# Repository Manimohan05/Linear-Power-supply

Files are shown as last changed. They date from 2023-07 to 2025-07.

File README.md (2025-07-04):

# Linear Power Supply Design

## Abstract

This project, part of the EN2111 Electronic Circuit Design module at the University of Moratuwa, focuses on designing a linear power supply with a maximum current limit of 100 mA, incorporating over-current protection. The power supply delivers a stable output voltage adjustable from 8V to 14V, robust against fluctuating input voltages (16V to 20V) and varying load conditions. This repository contains the project files, including schematics, PCB designs, calculations, and documentation, developed by Group 19 under the supervision of Dr. Thusapparan Subramaniam.

## Introduction

A linear power supply provides a stable, precise output voltage, unlike unregulated power supplies that vary with load and input voltage fluctuations. By using a linear regulator, the power supply maintains a consistent output voltage (adjustable from 8V to 14V), reduces ripple and noise in the output direct current, and includes current limiting to protect against over-current damage. Key performance metrics include:
- **Line Regulation**: The ability to maintain the specified output voltage despite input voltage variations (16V to 20V).
- **Load Regulation**: The ability to maintain the specified output voltage under varying load conditions (e.g., resistors from 6Ω to 5000Ω).
- **Over-Current Protection**: Limits the output current to ~100 mA to safeguard the power supply and connected circuits.

The worst-case tolerance for output voltage stability is the sum of line and load regulation percentages. This project demonstrates the design, implementation, and testing of a linear power supply to meet these requirements.

## Project Objectives

- Design a linear power supply with an adjustable output voltage of 8V to 14V.
- Implement a current limit of 100 mA with over-current protection.
- Ensure output stability against input voltage fluctuations (16V to 20V) and varying load conditions.
- Prototype the circuit on a breadboard and finalize with a PCB design using EasyEDA.
- Document the design process, calculations, and performance results.

## Key Features

- **Voltage Regulation**: Utilizes a Zener diode and resistors to achieve stable output with minimal ripple and noise.
- **Current Limiting**: Targeted at 100 mA, achieved ~103 mA due to component tolerances.
- **Transistor**: TIP31C selected for power dissipation capacity exceeding 1.2W [(20V - 8V) × 100 mA].
- **PCB Design**: Designed with EasyEDA, adhering to rules such as 0.152 mm clearance, 0.254 mm copper width, and a 46 mm × 31 mm board.
- **Testing**: Validated for line and load regulation across input voltages (16V to 20V) and load conditions.

## Setup Instructions

### Prerequisites

- **Software**:
  - EasyEDA for viewing/editing schematic and PCB files.
  - A PDF reader for documentation.
  - A spreadsheet viewer (e.g., Microsoft Excel, LibreOffice Calc) for calculation files.
- **Hardware** (for replication):
  - TIP31C transistor.
  - Zener diode (refer to project documentation for selection details).
  - Resistors, capacitors, and other components as specified in the report.
  - Breadboard and jumper wires for prototyping.
  - PCB fabrication service for the final board.

### Steps to Replicate

1. **Clone the Repository**:
   ```bash
   git clone https://github.com/<your-username>/Linear-Power-Supply.git
   cd Linear-Power-Supply
   ```

2. **Review Documentation**:
   - Open the project report PDF for details on calculations, schematics, and observations.
   - Refer to calculation files for input/output voltage ranges, Zener diode selection, and resistor values.

3. **Breadboard Implementation**:
   - Build the circuit on a breadboard using the schematic provided in the project files.
   - Test with input voltages from 16V to 20V, verifying output voltage (8V to 14V) and current limit (~100 mA).

4. **PCB Design**:
   - Open the EasyEDA schematic and PCB files.
   - Verify PCB design rules (e.g., 0.3 mm hole size, 46 mm × 31 mm board).
   - Use Gerber files for PCB fabrication.

5. **Testing**:
   - Test line regulation by setting the output to 8V and varying the input from 16V to 20V.
   - Test load regulation with resistors from 6Ω to 5000Ω.
   - Confirm current limitation at ~100 mA to ensure over-current protection.

## Observations

- **Output Voltage Range**: Achieved 6.8325V to 14.1534V, slightly wider than the target due to component tolerances.
- **Current Limitation**: Recorded at 103 mA, slightly above the 100 mA target.
- **Line Regulation**: Stable output (e.g., 8V) across input voltages from 16V to 20V, demonstrating effective regulation.
- **Load Regulation**: Consistent output voltage across load resistors from 6Ω to 5000Ω, as documented in the load variance table.

## Challenges

- **Component Selection**: Sourcing precise Zener diodes and resistors was challenging, leading to minor deviations in output.
- **Component Damage**: Improper connections during breadboard testing damaged some BC109 transistors.
- **Output Range**: Initial designs required iterative adjustments to achieve the target voltage range.

## License

This project is licensed under the MIT License. See the `LICENSE` file for details.

## Acknowledgments

- **Supervisors**: Dr. Thusapparan Subramaniam.
- **Institution**: Department of Electronic & Telecommunication Engineering, University of Moratuwa.
- **Tools**: EasyEDA for PCB design, breadboard for prototyping.

For more details, refer to the project report in the repository. Contributions or feedback are welcome—please open an issue or submit a pull request!

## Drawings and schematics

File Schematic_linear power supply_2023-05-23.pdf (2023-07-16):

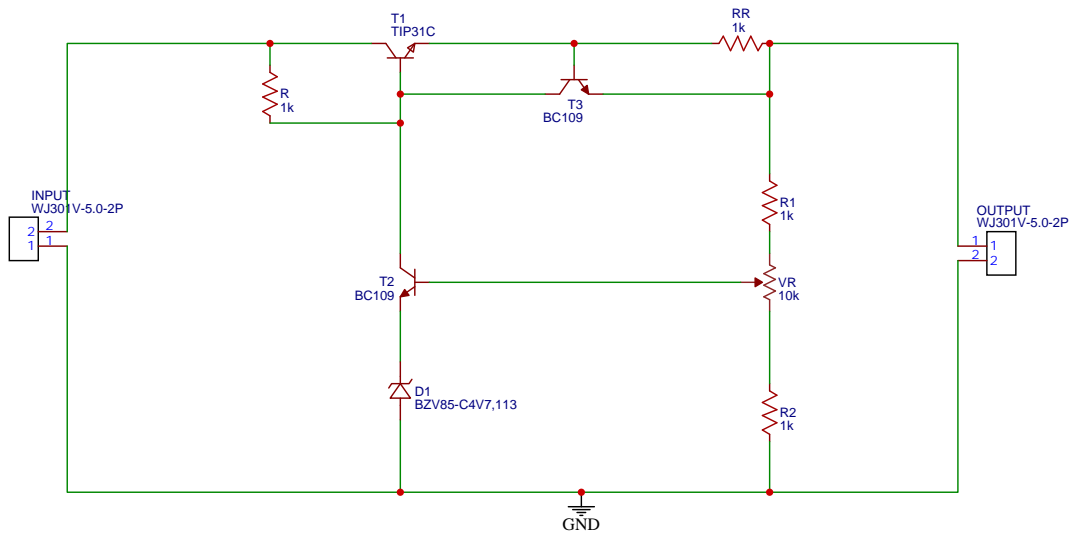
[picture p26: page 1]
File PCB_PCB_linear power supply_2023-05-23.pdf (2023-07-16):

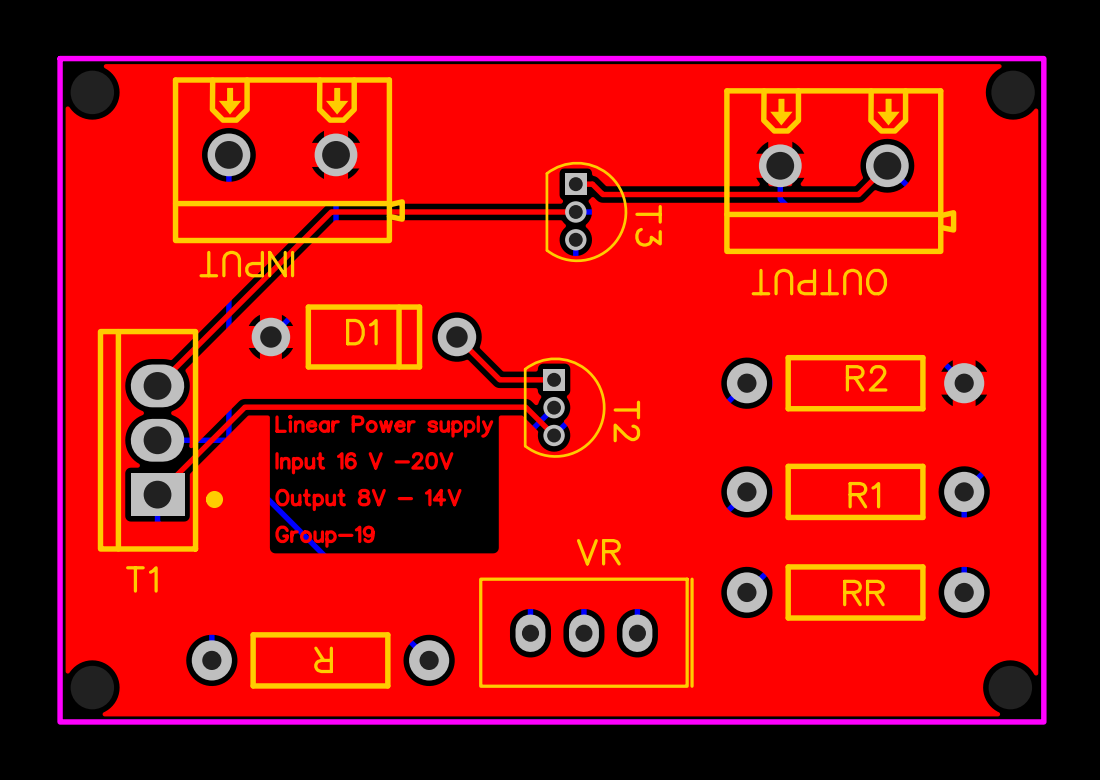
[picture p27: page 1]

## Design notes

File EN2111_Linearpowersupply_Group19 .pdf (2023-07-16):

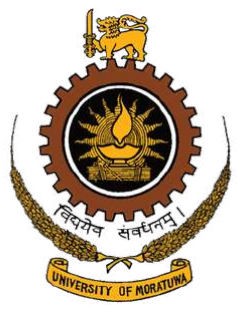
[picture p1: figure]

Department of Electronic & Telecommunication Engineering University of Moratuwa

EN2111 - ELECTRONIC CIRCUIT DESIGN

LINEAR POWER SUPPLY DESIGN

Supervisors:
Dr. Thayaparan Subramaniam
MANIMOHAN T. | 200377M
MIRANDA C.M.C.C. | 200396U
METHSARANI H.E.N | 200395P

This report is submitted as the fulfillment of Lab-03 of module EN2111

21st May 2023

ABSTRACT

We had to create a linear power supply with a maximum current restriction (also known as over-current protection).Our power source need to be able to deliver consistent output voltage for various variable output loads as well as to a fluctuating input line voltage.

This report explains the functionality of Linear power supply which can give output as from 8V to 14V.This is bassed on the module EN2111 - Electronic Circuit Design, Which is conducted by Dr. Thayaparan Subramaniam.

i

TABLE OF CONTENTS

2.4 Selection of variable
resistor(VR) 3

ii

LIST OF TABLES

1 | Current Limitation | | 8
2 | Line variance | 10
3 | load variance | 10
4 | List of components | 12
| LIST OF FIGURES
1 | Circuit | | 1
2 | Breadboard Implementation | | 5
3 | Breadboard Implementation | | 5
4 | Output voltages at minimum Input(16V) | | 6
5 | Output voltages at Input= 17V | | 6
6 | Output voltages at Input= 18V | | 6
7 | Output voltages at Input= 19V | | 7
8 | Output voltages at maximum Input(20V) | | 7
9 | Set Output voltage to 10V | | 7
10 | Set Output voltage to 10V and change the input | | 8
11 | Current Limitation-Vast range | | 9
12 | Current Limitation-Zoomed in small range | | 9
13 | Line Variance | 10
14 | Load Variance-Vast range | 11
15 | Load Variance-Zoomed in small range | 11
16 | Circuit simulation-Minimum Voltage | 12
17 | Circuit simulation-Maximum Voltage | 13
18 | PCB Schematic | 13
19 | PCB 2D View | 14
20 | PCB 3D model | 14

iii

### 1 INTRODUCTION OF LINEAR POWER SUPPLY

* Output voltage of an unregulated power supply will vary depending on the load and on variations in the AC supply voltage
* Linear regulator may be used to set the voltage to a precise value, stabilized against fluctuations in input voltage and load
* Regulator also greatly reduces the ripple and noise in the output direct current
* Linear regulators often provide current limiting, protecting the power supply and attached circuit from over-current
* Adjustable linear power supplies allow the output voltage to be adjusted over a range
* Line regulation is a measure of the circuit’s ability to maintain the specified output voltage with varying input voltage
* Load regulation is a measure of the circuit’s ability to maintain the specified output voltage under varying load conditions.
* Load regulation and Line regulation values apply to the output
* The worst case value is the addition of both line and load tolerance percentages.

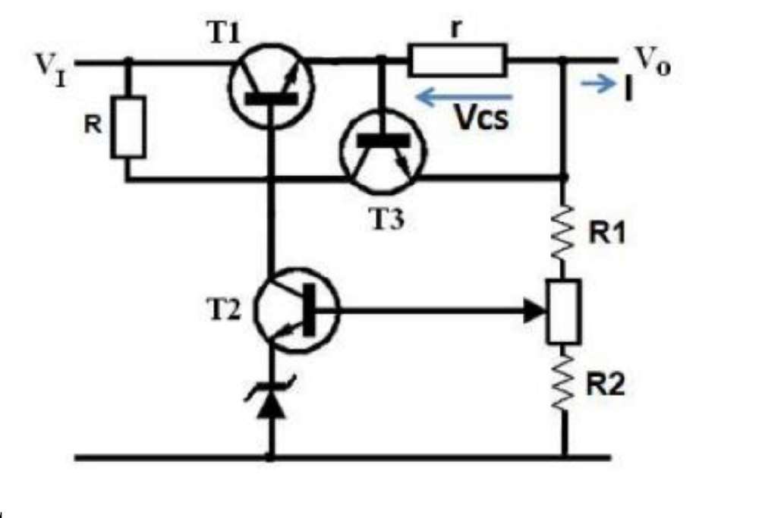
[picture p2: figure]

Figure 1 — Circuit

1

### 2 CALCULATIONS

### 2.1 Calculate Input & Output ranges

* Group Number = 19
* Typical input voltage = 14V + Reminder of (19/5)= 14 + 4 V = 18 V * Input voltage range Vi = Typical Input voltage ± 2 V = 18 ± 2 V
* Current Limitation = 100 mA (for all groups)
* Mid output voltage Vo = Vi - 8 + Reminder of (19 /3) = 11 V
* Output voltage range = Mid output voltage ± 3 V = 11 ± 3 V

### 2.2 Selection of Zener

Vomin > Vz + Vbe
Vz < 7.4V

Therefore we decided to take more zener diode with 4.7V zener voltage.

### 2.3 Calculate R1 and R2

Vo.

R2
R1 + R2

= (VZ + VBE)

VZ = 4.7V

VBE = 0.62V

Vo.

R2
R1 + R2

= 5.32V

(1)

To calculate the maximum ratio between R1 and R2

VOMax = 15V

1 +

R1
R2

=

15V
5.32V
R1
R2

= 2.8195 − 1 = 1.8915

R1

R2 Max

= 1.8915

(2)

To calculate the minimum ratio between R1 and R2

VOM in = 7V

1 +

R1
R2

=

7V
5.32V
R1
R2

= 1.3158 − 1 = 0.3158

R1

R2 M in

= 0.3158

(3)

2

EN 2111:Linear Power Supply Design

let R2 = 5kΩ
For VOMax→ R1 = 1.8195 × 5kΩ = 9.0975kΩ For VOM in→ R1 = 0.3158 × 5kΩ = 1.579kΩ δR1 = (0.0975 − 1.579)kΩ

δR1 = 7.5185kΩ

Therefore, we have selected R1 as 1.5 kohms
R2 as 5 kohms

### 2.4 Selection of variable resistor(VR)

To find VR

VR ≥ δR1 = 7.5185kΩ

Therefore, we have selected 10 kohms variable resistor.

### 2.5 Calculate value of R

To calculate the value of R

IRmin ≥

ILMax
β

+ IKnee

16 − (14 + 0.62)
R

≥

100 × 10−3

100

+ 1 × 10−3

R ≤

1.38 × 10−3

2
R ≤ 0.69 × 10−3

R ≤ 690Ω

(4)

Therefore, we have selected R as 650 Ω

### 2.6 Calculate value of r

To calculate the value of r
To make T3 transistor in active region, the voltage across the base and emitter must be 0.62V, hence VcE must be 0.62V. Since 100mA should be the maximum current allowed to flow through the resistor,

r ≥

0.62V
100 × 10−3A
r ≥ 6.2Ω

(5)

Therefore, we have selected r as 6.8 Ω

### 2.7 Selection of Transistor

T1 transistor’s maximum power dissipation is
(VI max − Vo min) · Imax = (20V − 8V ) · 100mA = 1.2W.
Therefore we chose TIP31C transistor which has a power rating higher than 1.2W.

### 3 METHODOLOGY & OBSERVATIONS

### 3.1 Functionality description

* Current limiting should be 100 mA
* We should be able to change the input and same time output voltage should be constant * Output voltage should be adjustable

### 3.2 Breadboard Implementation

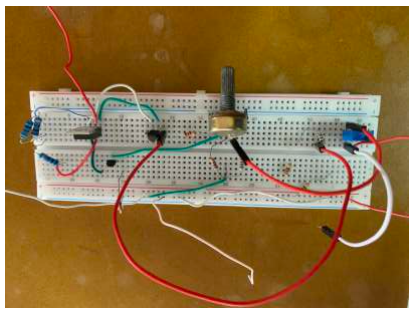
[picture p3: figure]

Figure 2 — Breadboard Implementation

### 3.3 Observations

We achieved a voltage range of 6.8325 V to 14.1534 V and a maximum current of 103 mA due to changes in resistors and impedance.

### 3.3.1 Circuit connections

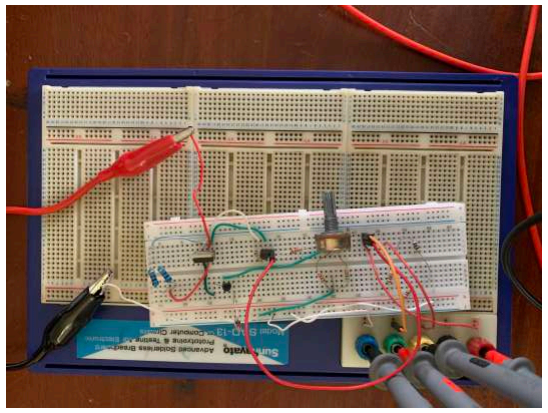
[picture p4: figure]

Figure 3 — Breadboard Implementation

5

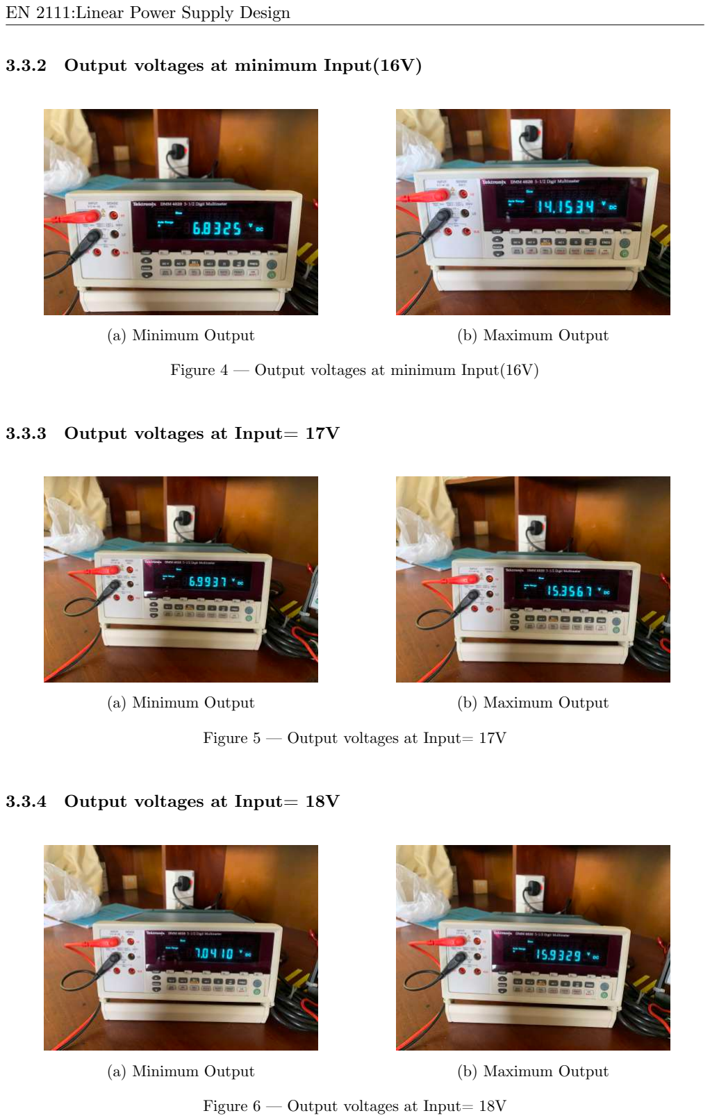
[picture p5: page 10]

### 3.3.2 Output voltages at minimum Input(16V)

(a) Minimum Output | (b) Maximum Output

Figure 4 — Output voltages at minimum Input(16V)

### 3.3.3 Output voltages at Input= 17V

(a) Minimum Output | (b) Maximum Output

Figure 5 — Output voltages at Input= 17V

### 3.3.4 Output voltages at Input= 18V

(a) Minimum Output | (b) Maximum Output

Figure 6 — Output voltages at Input= 18V

### 3.3.5 Output voltages at Input= 19V

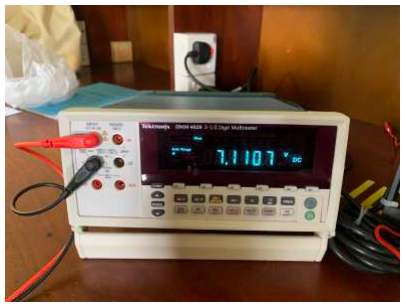
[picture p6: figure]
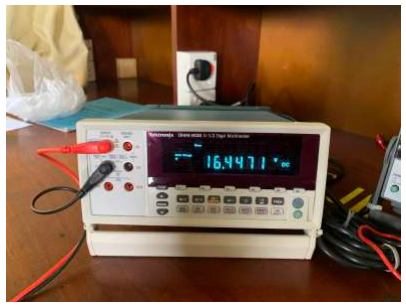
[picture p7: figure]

(a) Minimum Output | (b) Maximum Output

Figure 7 — Output voltages at Input= 19V

### 3.3.6 Output voltages at maximum Input(20V)

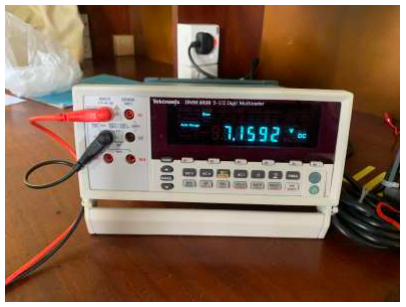
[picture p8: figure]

(a) Minimum Output | (b) Maximum Output

Figure 8 — Output voltages at maximum Input(20V)

### 3.3.7 Set Output voltage to 10V

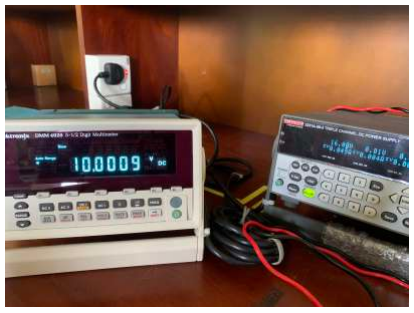
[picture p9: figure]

Figure 9 — Set Output voltage to 10V

### 3.3.8 Change the Input at particular output voltage = 10V

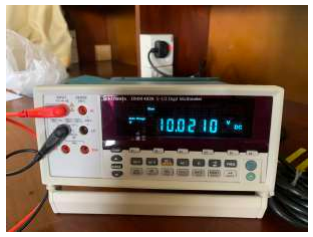
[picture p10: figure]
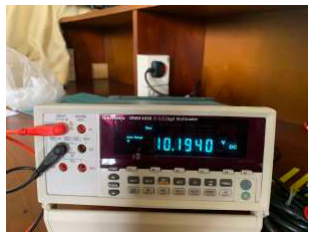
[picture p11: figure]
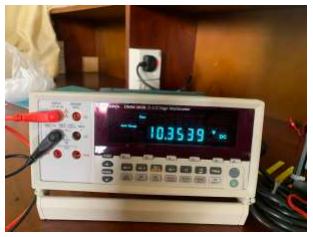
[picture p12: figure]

(a) Input = 16V | (b) Input = 17V | (c) Input = 18V

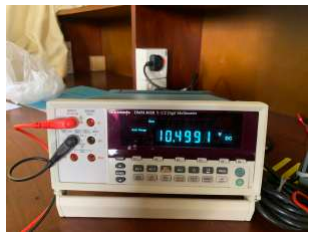
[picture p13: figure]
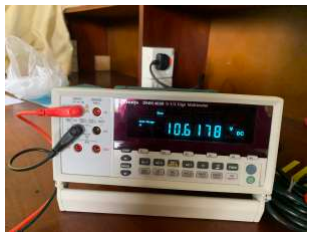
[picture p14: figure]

(d) Input = 19V | (e) Input = 20V

Figure 10 — Set Output voltage to 10V and change the input

### 3.4 Results of Laboratory Implementation

### 3.4.1 Current Limitation

Load Resistor(ohms) | Load current(mA)
6 | 103.00
25 | 102.00
56 | 99.60
71 | 99.40
240 | 40.20
500 | 21.05
750 | 13.62
1000 | 10.23
2000 | 4.02
3000 | 2.49
4000 | 2.01
5000 | 1.84

Table 1 — Current Limitation

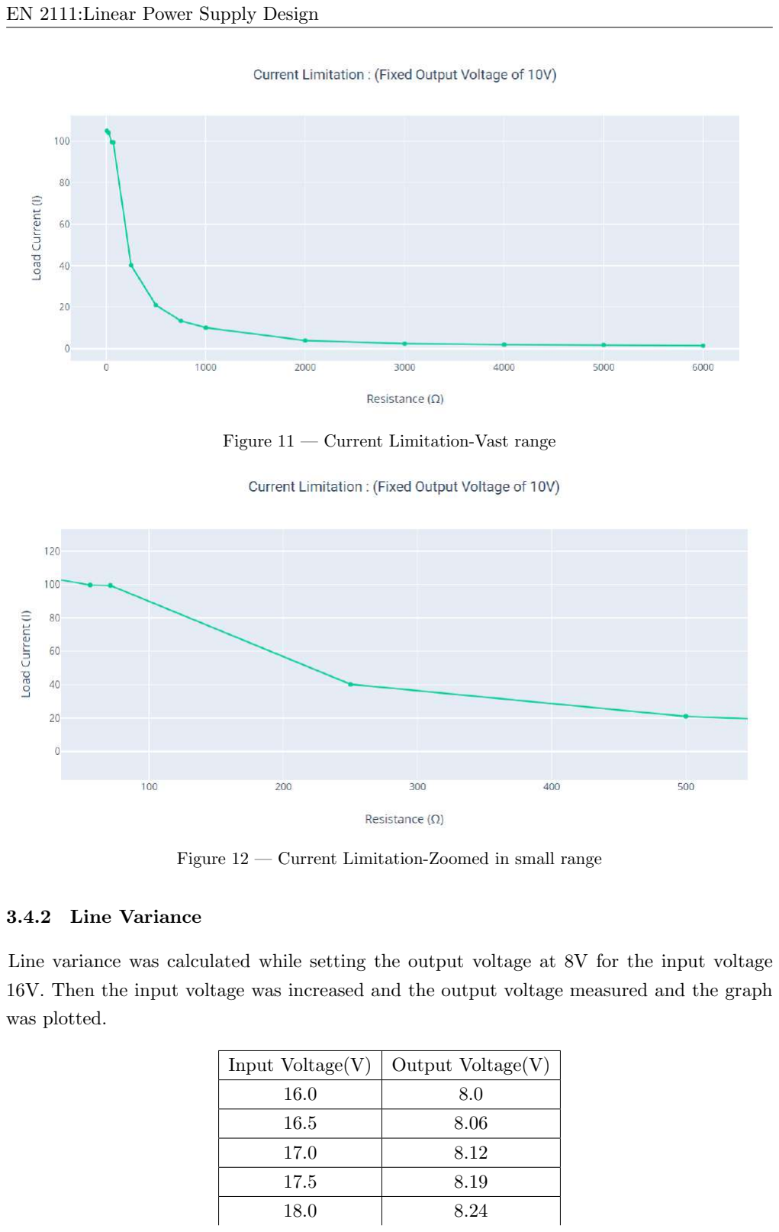
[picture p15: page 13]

Figure 11 — Current Limitation-Vast range

Figure 12 — Current Limitation-Zoomed in small range

### 3.4.2 Line Variance

Line variance was calculated while setting the output voltage at 8V for the input voltage 16V. Then the input voltage was increased and the output voltage measured and the graph was plotted.

Input Voltage(V) | Output Voltage(V)
16.0 | 8.0
16.5 | 8.06
17.0 | 8.12
17.5 | 8.19
18.0 | 8.24

Input Voltage(V) | Output Voltage(V)
18.5 | 8.30
19.0 | 8.35
19.5 | 8.41
20.0 | 8.47

Table 2 — Line variance

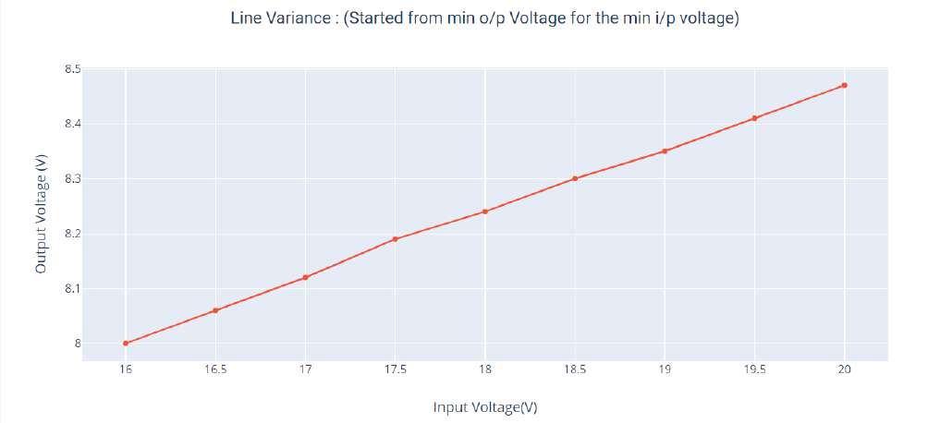
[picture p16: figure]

Figure 13 — Line Variance

### 3.4.3 Load Variance

Load Resistor(ohms) | Output Voltage(V)
6 | 0.98
25 | 3.54
56 | 6.60
71 | 8.00
240 | 9.95
500 | 9.98
750 | 9.99
1000 | 10.01
2000 | 10.02
3000 | 10.02
4000 | 10.03
5000 | 10.04

Table 3 — load variance

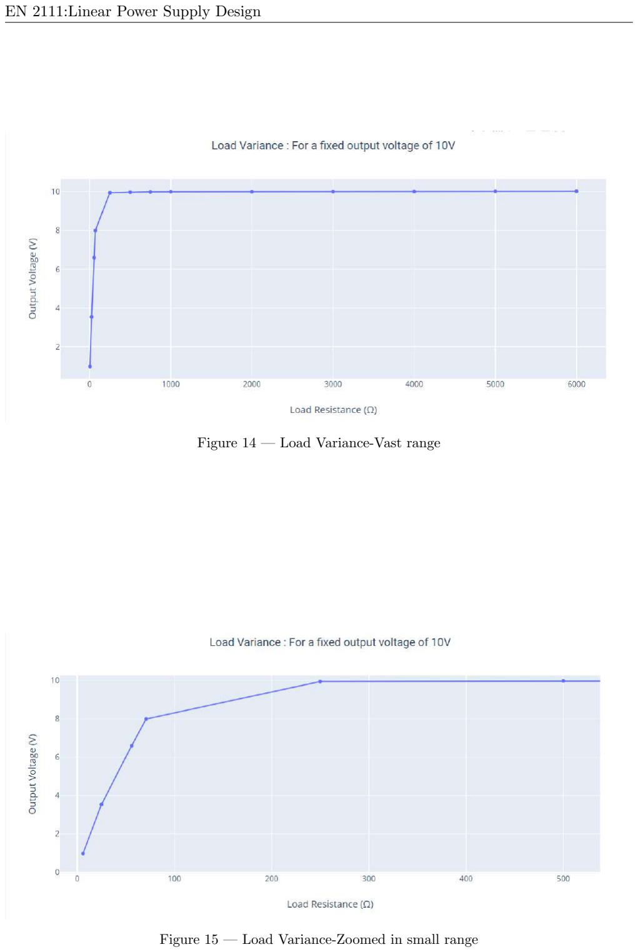
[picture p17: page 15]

Figure 14 — Load Variance-Vast range

Figure 15 — Load Variance-Zoomed in small range

### 4 DESIGN OF LINEAR POWER SUPPLY

### 4.1 List of components

As this is an analog linear power regulation circuit, we used a variety of transistors and resistors.

Item | Quantity | Description
TIP31C | 1 | Medium power amplification, able to tolerate high voltages
BC109 | 2 | A General NPN transistor.
4.7 V zener | 1 | Maintain voltage across it at 4.7V when maximum current passes
Resistor(5KΩ) | 1
Resistor(1.5KΩ) | 1
Resistor(6.8 Ω) | 1
Resistor(650 Ω) | 1
10kΩT rimmer | 1 | We can get any resistance between 0 and 10000 ohms

Table 4 — List of components

### 4.2 Circuit Simulation Diagram

The simulation results for the computed values we obtained are shown in the photos below. Multisim was the simulation program that we employed.

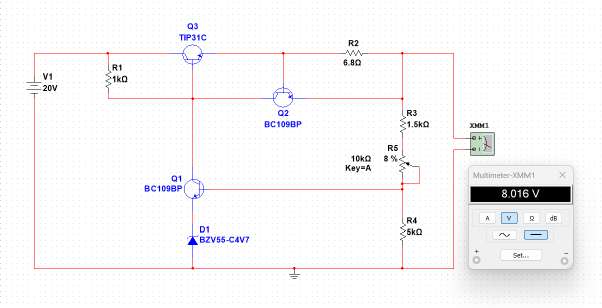
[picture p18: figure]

Figure 16 — Circuit simulation-Minimum Voltage

12

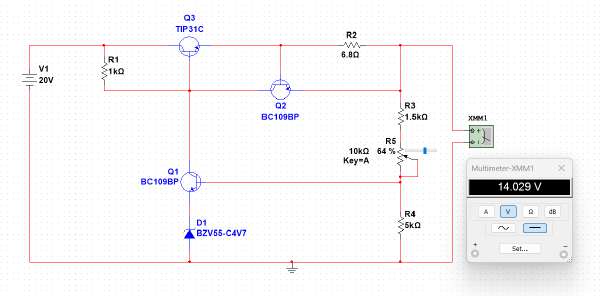
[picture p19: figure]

Figure 17 — Circuit simulation-Maximum Voltage

### 4.3 PCB Design

The schematic of the circuit was drawn first and the PCB was designed accordingly using Easyeda.

### 4.3.1 PCB Schematic

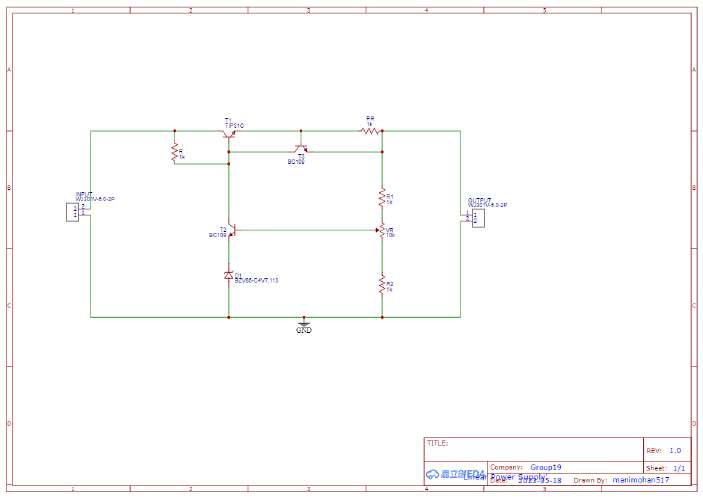
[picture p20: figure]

Figure 18 — PCB Schematic

### 4.3.2 PCB Design rules

* PCB length – 46 mm
* PCB width - 31 mm
* PCB clearance between two copper lines - 0.152 mm * width of copper wire - 0.254 mm
* Hole size - 0.3 mm

### 4.3.3 PCB Footprint

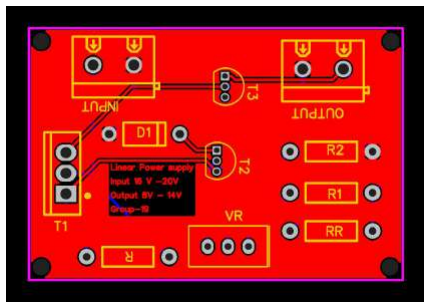
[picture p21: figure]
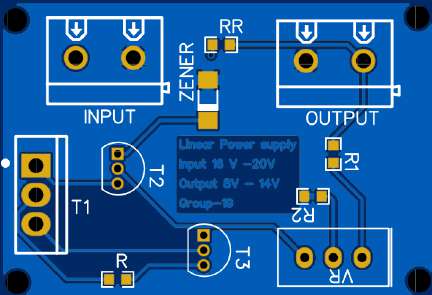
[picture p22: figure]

(a) PCB Footprint | (b) Layered View

Figure 19 — PCB 2D View

### 4.3.4 PCB 3D Model

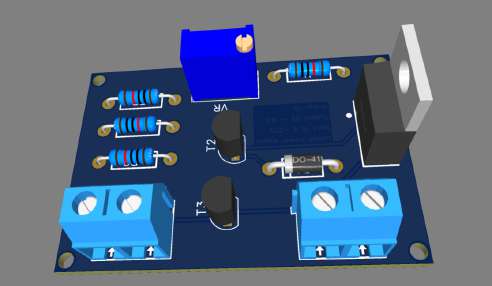
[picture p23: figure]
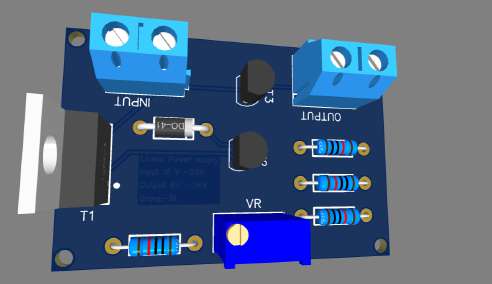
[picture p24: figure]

(a) (b)

Figure 20 — PCB 3D model

### 5 DISCUSSIONS & REEFERENCES

### 5.1 Discussions

There were various challenges, which we had to face during the implementing this Circuit. The obstacles we had to go through were stated follow.

* Finding the appropriate zener and the power transistor was difficult.
* We couldn’t able to find exact values for R and r
* Initially we couldn’t able to get the output range which assigned for us. * some BC109 burnt due to improper connections

### 5.2 References

Below is an appendix with data sheets for the utilized components:

1. BC109 (https://pdf1.alldatasheet.com/datasheet-pdf/view/16090/PHILIPS/BC109.html)
2. TIP31C (https://pdf1.alldatasheet.com/datasheet-pdf/view/968896/JIANGSU/TIP31C.html)
3. C4V7 (https://www.alldatasheet.com/datasheet-pdf/pdf/95153/ZETEX/C4V7.html)

15

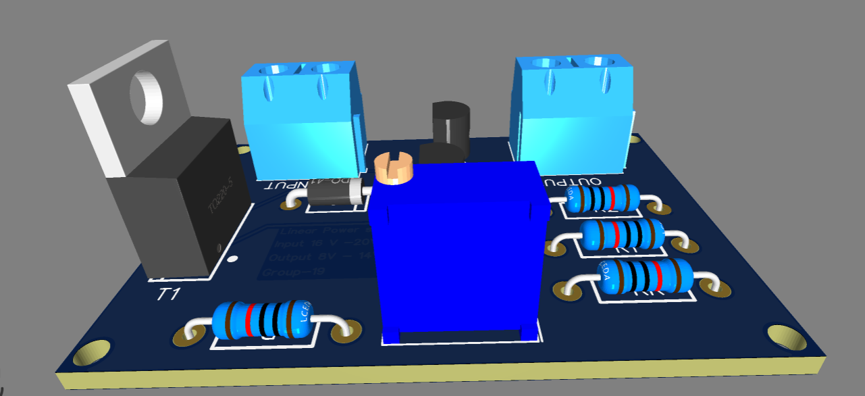
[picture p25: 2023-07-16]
3d (3).png
